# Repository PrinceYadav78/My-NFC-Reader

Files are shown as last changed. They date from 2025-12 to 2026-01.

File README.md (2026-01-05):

# ESP32 NFC Reader

This is my very own prototype of an NFC Reader, built using the ESP32 microcontroller! It’s a compact, wireless module designed to read and interact with NFC tags and cards.

# How to Use
Plug in a USB cable into the receptacle. Install the ESP32IDE for configuration of the firmware.

# Images

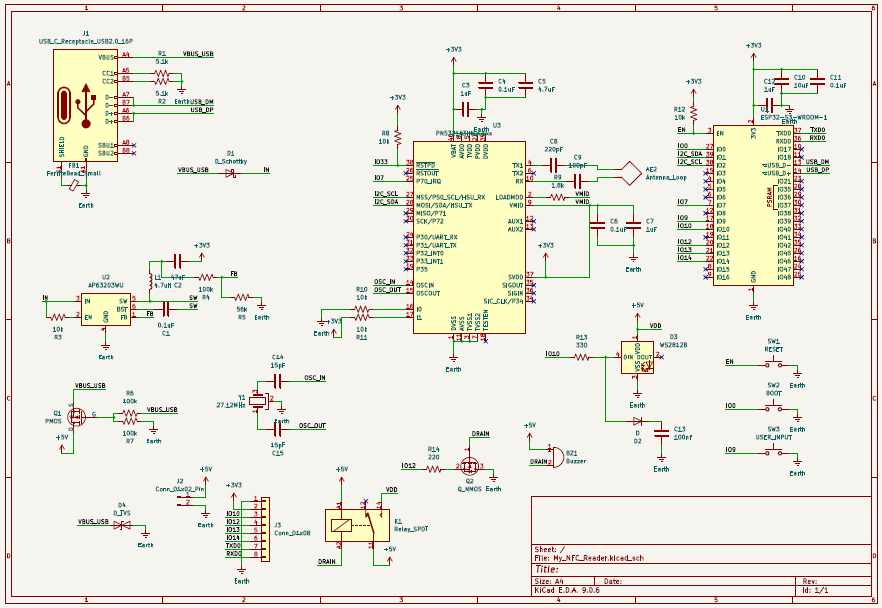
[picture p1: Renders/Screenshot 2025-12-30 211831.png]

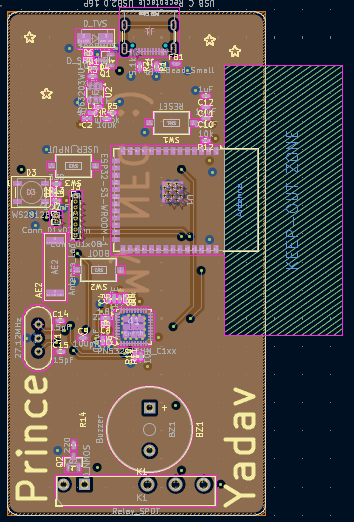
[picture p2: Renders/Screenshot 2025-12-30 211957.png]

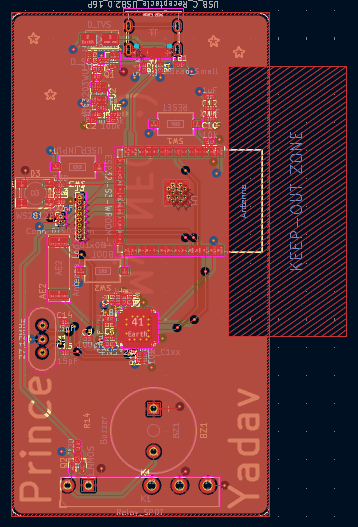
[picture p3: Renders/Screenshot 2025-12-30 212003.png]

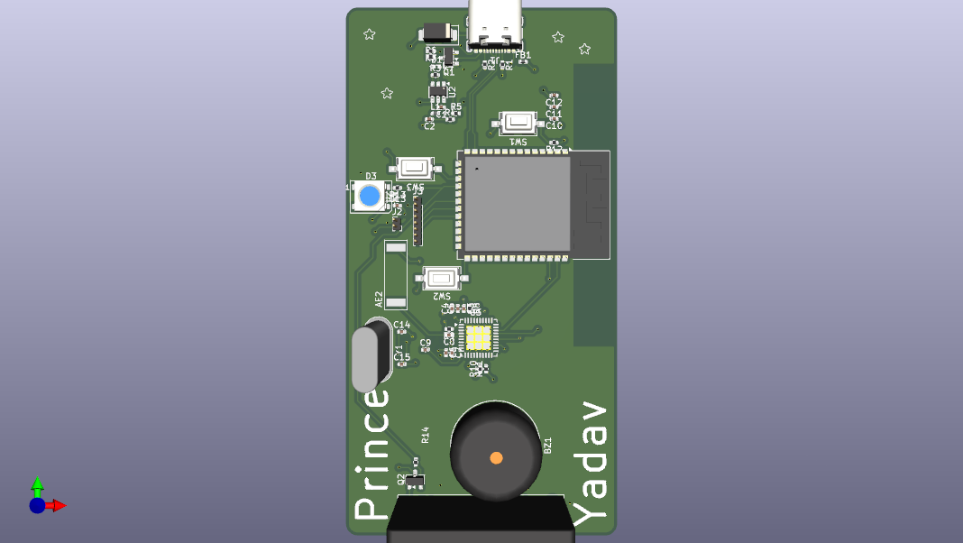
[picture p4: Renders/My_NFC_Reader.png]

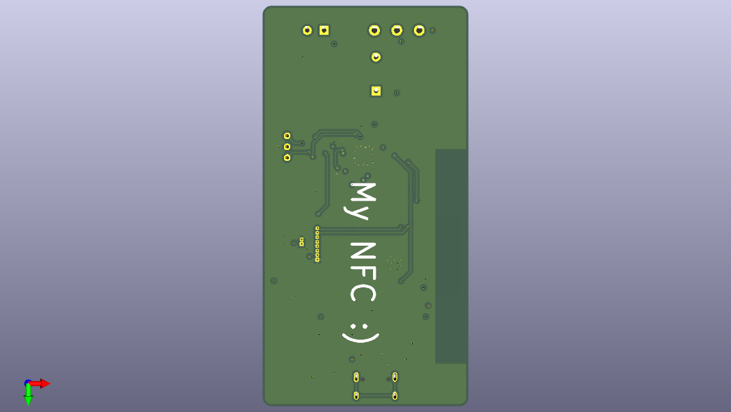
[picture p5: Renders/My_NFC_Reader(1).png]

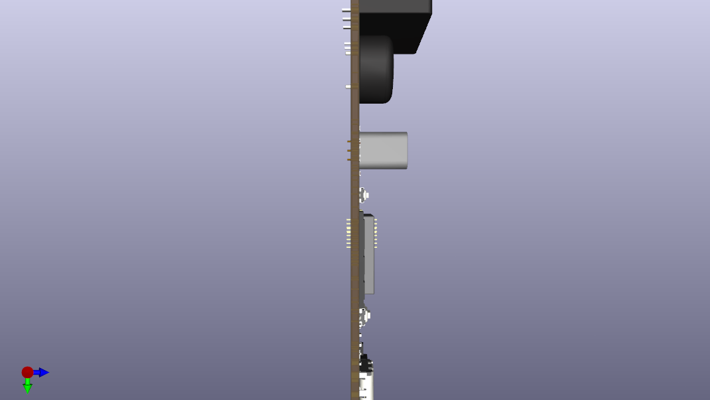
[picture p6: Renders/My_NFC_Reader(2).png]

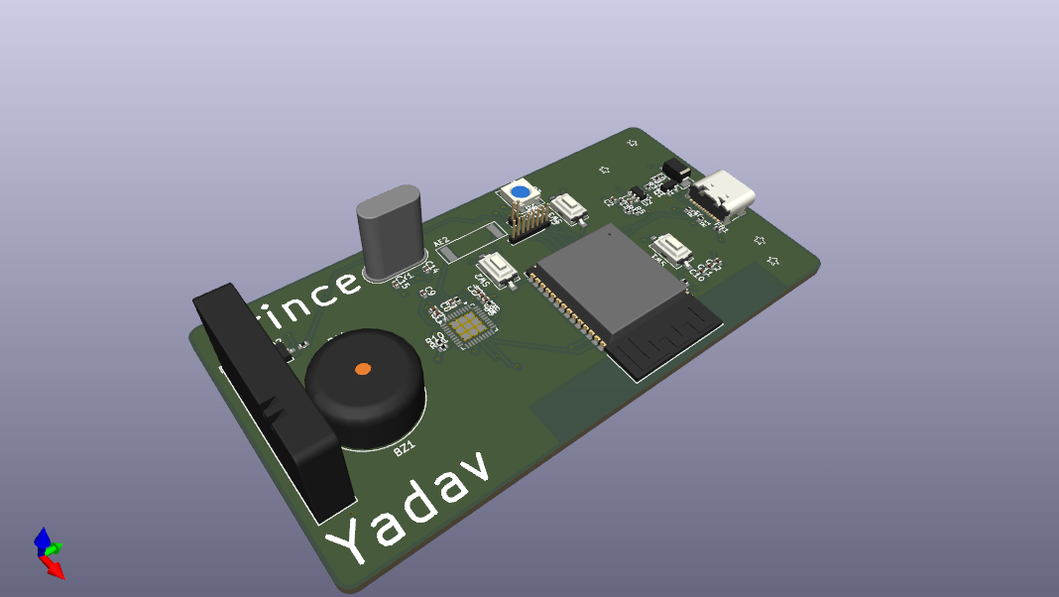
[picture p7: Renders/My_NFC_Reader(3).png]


# BOM
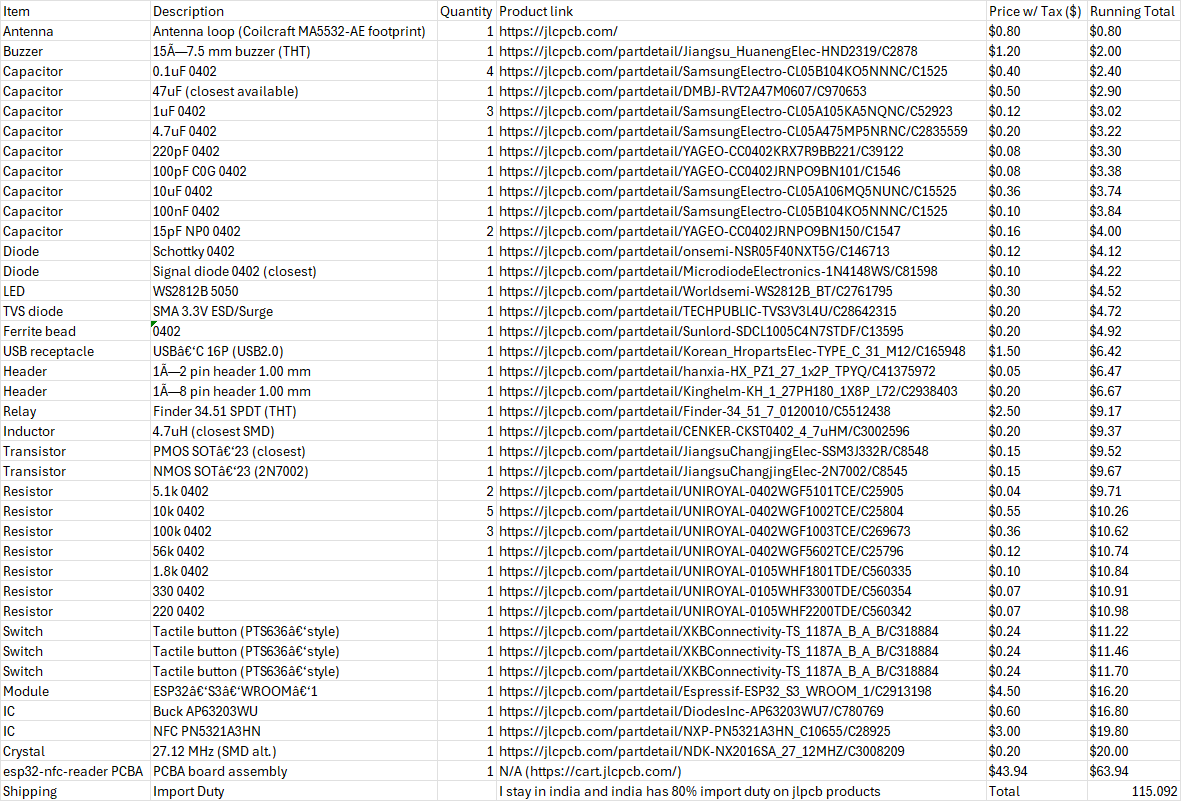
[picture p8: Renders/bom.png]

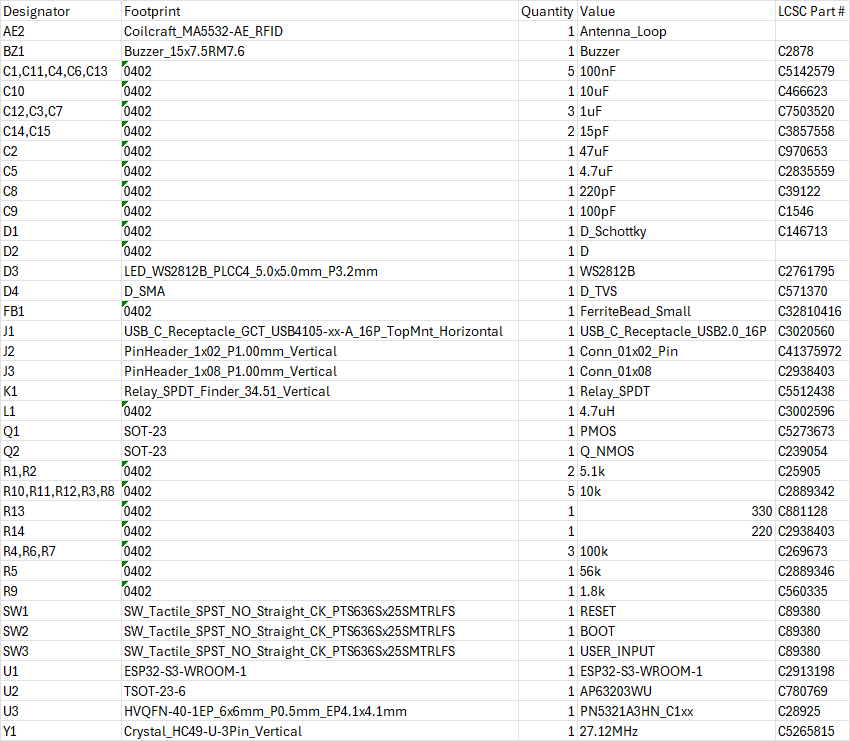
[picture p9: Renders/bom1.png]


## Cart



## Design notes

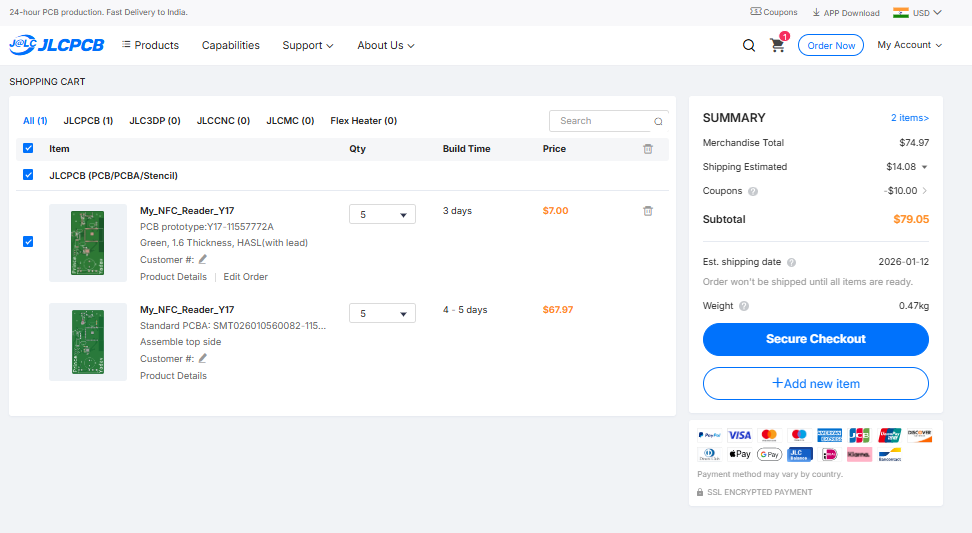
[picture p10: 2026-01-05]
Renders/Screenshot 2026-01-05 065034.png

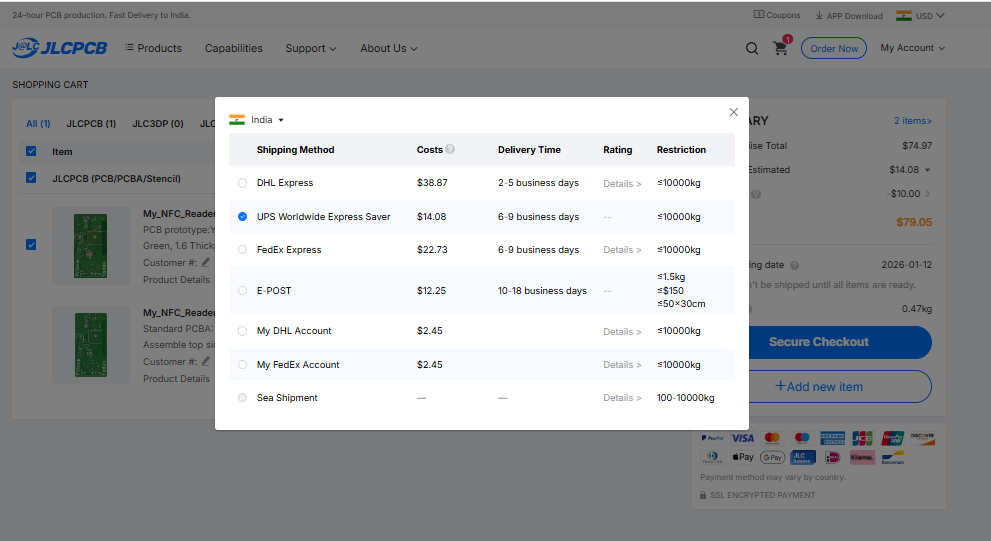
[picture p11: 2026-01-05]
Renders/Screenshot 2026-01-05 065027.png

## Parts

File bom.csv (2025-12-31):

Item | Description | Quantity | Product link | Price w/ Tax ($) | Running Total
Antenna | Antenna loop (Coilcraft MA5532-AE footprint) | 1 | https://jlcpcb.com/ | $0.80 | $0.80
Buzzer | 15×7.5 mm buzzer (THT) | 1 | https://jlcpcb.com/partdetail/Jiangsu_HuanengElec-HND2319/C2878 | $1.20 | $2.00
Capacitor | 0.1uF 0402 | 4 | https://jlcpcb.com/partdetail/SamsungElectro-CL05B104KO5NNNC/C1525 | $0.40 | $2.40
Capacitor | 47uF (closest available) | 1 | https://jlcpcb.com/partdetail/DMBJ-RVT2A47M0607/C970653 | $0.50 | $2.90
Capacitor | 1uF 0402 | 3 | https://jlcpcb.com/partdetail/SamsungElectro-CL05A105KA5NQNC/C52923 | $0.12 | $3.02
Capacitor | 4.7uF 0402 | 1 | https://jlcpcb.com/partdetail/SamsungElectro-CL05A475MP5NRNC/C2835559 | $0.20 | $3.22
Capacitor | 220pF 0402 | 1 | https://jlcpcb.com/partdetail/YAGEO-CC0402KRX7R9BB221/C39122 | $0.08 | $3.30
Capacitor | 100pF C0G 0402 | 1 | https://jlcpcb.com/partdetail/YAGEO-CC0402JRNPO9BN101/C1546 | $0.08 | $3.38
Capacitor | 10uF 0402 | 1 | https://jlcpcb.com/partdetail/SamsungElectro-CL05A106MQ5NUNC/C15525 | $0.36 | $3.74
Capacitor | 100nF 0402 | 1 | https://jlcpcb.com/partdetail/SamsungElectro-CL05B104KO5NNNC/C1525 | $0.10 | $3.84
Capacitor | 15pF NP0 0402 | 2 | https://jlcpcb.com/partdetail/YAGEO-CC0402JRNPO9BN150/C1547 | $0.16 | $4.00
Diode | Schottky 0402 | 1 | https://jlcpcb.com/partdetail/onsemi-NSR05F40NXT5G/C146713 | $0.12 | $4.12
Diode | Signal diode 0402 (closest) | 1 | https://jlcpcb.com/partdetail/MicrodiodeElectronics-1N4148WS/C81598 | $0.10 | $4.22
LED | WS2812B 5050 | 1 | https://jlcpcb.com/partdetail/Worldsemi-WS2812B_BT/C2761795 | $0.30 | $4.52
TVS diode | SMA 3.3V ESD/Surge | 1 | https://jlcpcb.com/partdetail/TECHPUBLIC-TVS3V3L4U/C28642315 | $0.20 | $4.72
Ferrite bead | 0402 | 1 | https://jlcpcb.com/partdetail/Sunlord-SDCL1005C4N7STDF/C13595 | $0.20 | $4.92
USB receptacle | USB‑C 16P (USB2.0) | 1 | https://jlcpcb.com/partdetail/Korean_HropartsElec-TYPE_C_31_M12/C165948 | $1.50 | $6.42
Header | 1×2 pin header 1.00 mm | 1 | https://jlcpcb.com/partdetail/hanxia-HX_PZ1_27_1x2P_TPYQ/C41375972 | $0.05 | $6.47
Header | 1×8 pin header 1.00 mm | 1 | https://jlcpcb.com/partdetail/Kinghelm-KH_1_27PH180_1X8P_L72/C2938403 | $0.20 | $6.67
Relay | Finder 34.51 SPDT (THT) | 1 | https://jlcpcb.com/partdetail/Finder-34_51_7_0120010/C5512438 | $2.50 | $9.17
Inductor | 4.7uH (closest SMD) | 1 | https://jlcpcb.com/partdetail/CENKER-CKST0402_4_7uHM/C3002596 | $0.20 | $9.37
Transistor | PMOS SOT‑23 (closest) | 1 | https://jlcpcb.com/partdetail/JiangsuChangjingElec-SSM3J332R/C8548 | $0.15 | $9.52
Transistor | NMOS SOT‑23 (2N7002) | 1 | https://jlcpcb.com/partdetail/JiangsuChangjingElec-2N7002/C8545 | $0.15 | $9.67
Resistor | 5.1k 0402 | 2 | https://jlcpcb.com/partdetail/UNIROYAL-0402WGF5101TCE/C25905 | $0.04 | $9.71
Resistor | 10k 0402 | 5 | https://jlcpcb.com/partdetail/UNIROYAL-0402WGF1002TCE/C25804 | $0.55 | $10.26
Resistor | 100k 0402 | 3 | https://jlcpcb.com/partdetail/UNIROYAL-0402WGF1003TCE/C269673 | $0.36 | $10.62
Resistor | 56k 0402 | 1 | https://jlcpcb.com/partdetail/UNIROYAL-0402WGF5602TCE/C25796 | $0.12 | $10.74
Resistor | 1.8k 0402 | 1 | https://jlcpcb.com/partdetail/UNIROYAL-0105WHF1801TDE/C560335 | $0.10 | $10.84
Resistor | 330 0402 | 1 | https://jlcpcb.com/partdetail/UNIROYAL-0105WHF3300TDE/C560354 | $0.07 | $10.91
Resistor | 220 0402 | 1 | https://jlcpcb.com/partdetail/UNIROYAL-0105WHF2200TDE/C560342 | $0.07 | $10.98
Switch | Tactile button (PTS636‑style) | 1 | https://jlcpcb.com/partdetail/XKBConnectivity-TS_1187A_B_A_B/C318884 | $0.24 | $11.22
Switch | Tactile button (PTS636‑style) | 1 | https://jlcpcb.com/partdetail/XKBConnectivity-TS_1187A_B_A_B/C318884 | $0.24 | $11.46
Switch | Tactile button (PTS636‑style) | 1 | https://jlcpcb.com/partdetail/XKBConnectivity-TS_1187A_B_A_B/C318884 | $0.24 | $11.70
Module | ESP32‑S3‑WROOM‑1 | 1 | https://jlcpcb.com/partdetail/Espressif-ESP32_S3_WROOM_1/C2913198 | $4.50 | $16.20
IC | Buck AP63203WU | 1 | https://jlcpcb.com/partdetail/DiodesInc-AP63203WU7/C780769 | $0.60 | $16.80
IC | NFC PN5321A3HN | 1 | https://jlcpcb.com/partdetail/NXP-PN5321A3HN_C10655/C28925 | $3.00 | $19.80
Crystal | 27.12 MHz (SMD alt.) | 1 | https://jlcpcb.com/partdetail/NDK-NX2016SA_27_12MHZ/C3008209 | $0.20 | $20.00
esp32-nfc-reader PCBA | PCBA board assembly | 1 | N/A (https://cart.jlcpcb.com/) | $43.94 | $63.94
Shipping | Import Duty |  | I stay in india and india has 80% import duty on jlpcb products | Total | 115.092

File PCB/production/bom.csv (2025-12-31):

Designator | Footprint | Quantity | Value | LCSC Part #
AE2 | Coilcraft_MA5532-AE_RFID | 1 | Antenna_Loop
BZ1 | Buzzer_15x7.5RM7.6 | 1 | Buzzer
C1, C11, C4, C6 | 0402 | 4 | 0.1uF
C10 | 0402 | 1 | 10uF
C12, C3, C7 | 0402 | 3 | 1uF
C13 | 0402 | 1 | 100nF
C14, C15 | 0402 | 2 | 15pF
C2 | 0402 | 1 | 47uF
C5 | 0402 | 1 | 4.7uF
C8 | 0402 | 1 | 220pF
C9 | 0402 | 1 | 100pF
D1 | 0402 | 1 | D_Schottky
D2 | 0402 | 1 | D
D3 | LED_WS2812B_PLCC4_5.0x5.0mm_P3.2mm | 1 | WS2812B
D4 | D_SMA | 1 | D_TVS
FB1 | 0402 | 1 | FerriteBead_Small
J1 | USB_C_Receptacle_GCT_USB4105-xx-A_16P_TopMnt_Horizontal | 1 | USB_C_Receptacle_USB2.0_16P
J2 | PinHeader_1x02_P1.00mm_Vertical | 1 | Conn_01x02_Pin
J3 | PinHeader_1x08_P1.00mm_Vertical | 1 | Conn_01x08
K1 | Relay_SPDT_Finder_34.51_Vertical | 1 | Relay_SPDT
L1 | 0402 | 1 | 4.7uH
Q1 | SOT-23 | 1 | PMOS
Q2 | SOT-23 | 1 | Q_NMOS
R1, R2 | 0402 | 2 | 5.1k
R10, R11, R12, R3, R8 | 0402 | 5 | 10k
R13 | 0402 | 1 | 330
R14 | 0402 | 1 | 220
R4, R6, R7 | 0402 | 3 | 100k
R5 | 0402 | 1 | 56k
R9 | 0402 | 1 | 1.8k
SW1 | SW_Tactile_SPST_NO_Straight_CK_PTS636Sx25SMTRLFS | 1 | RESET
SW2 | SW_Tactile_SPST_NO_Straight_CK_PTS636Sx25SMTRLFS | 1 | BOOT
SW3 | SW_Tactile_SPST_NO_Straight_CK_PTS636Sx25SMTRLFS | 1 | USER_INPUT
U1 | ESP32-S3-WROOM-1 | 1 | ESP32-S3-WROOM-1
U2 | TSOT-23-6 | 1 | AP63203WU
U3 | HVQFN-40-1EP_6x6mm_P0.5mm_EP4.1x4.1mm | 1 | PN5321A3HN_C1xx
Y1 | Crystal_HC49-U-3Pin_Vertical | 1 | 27.12MHz

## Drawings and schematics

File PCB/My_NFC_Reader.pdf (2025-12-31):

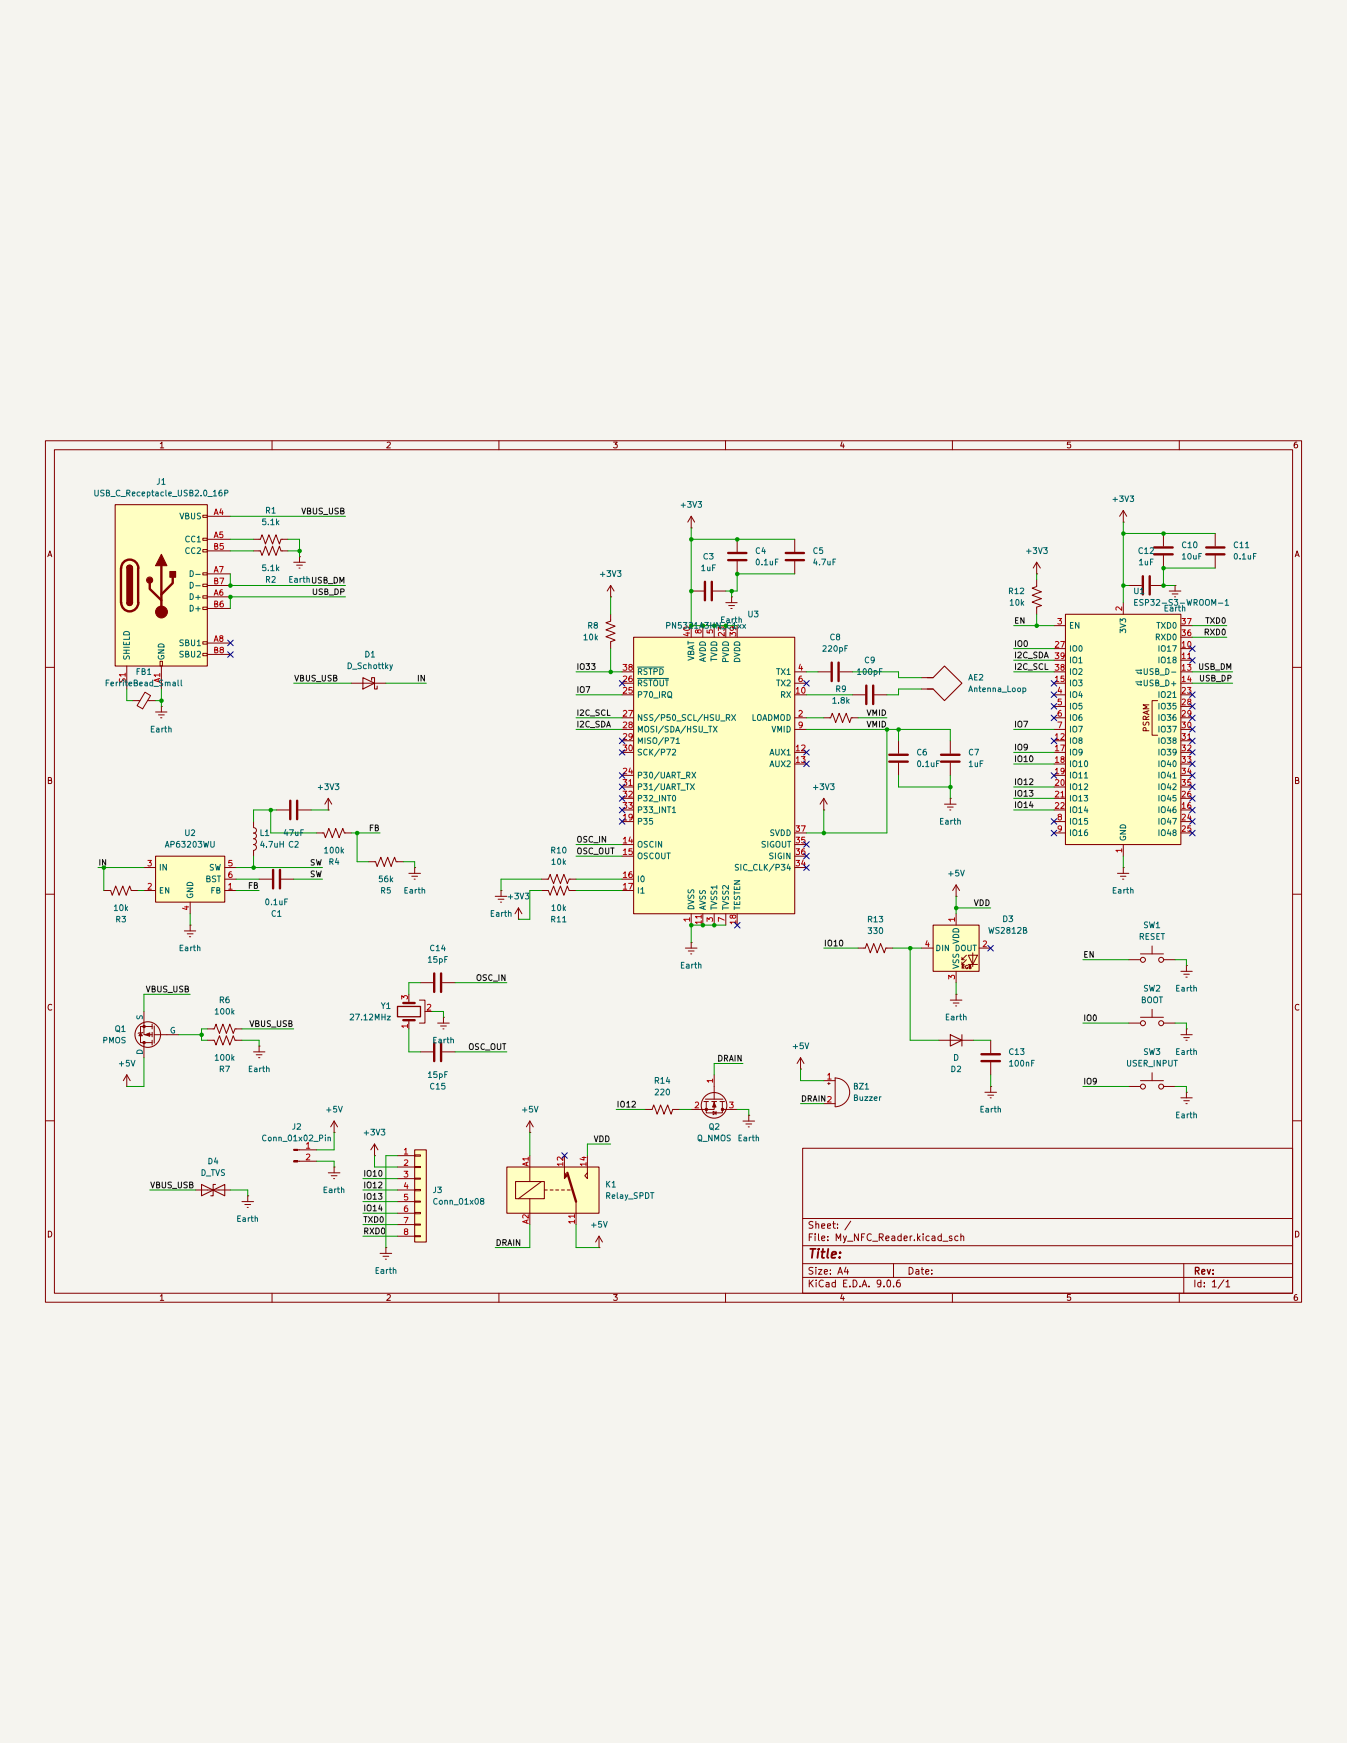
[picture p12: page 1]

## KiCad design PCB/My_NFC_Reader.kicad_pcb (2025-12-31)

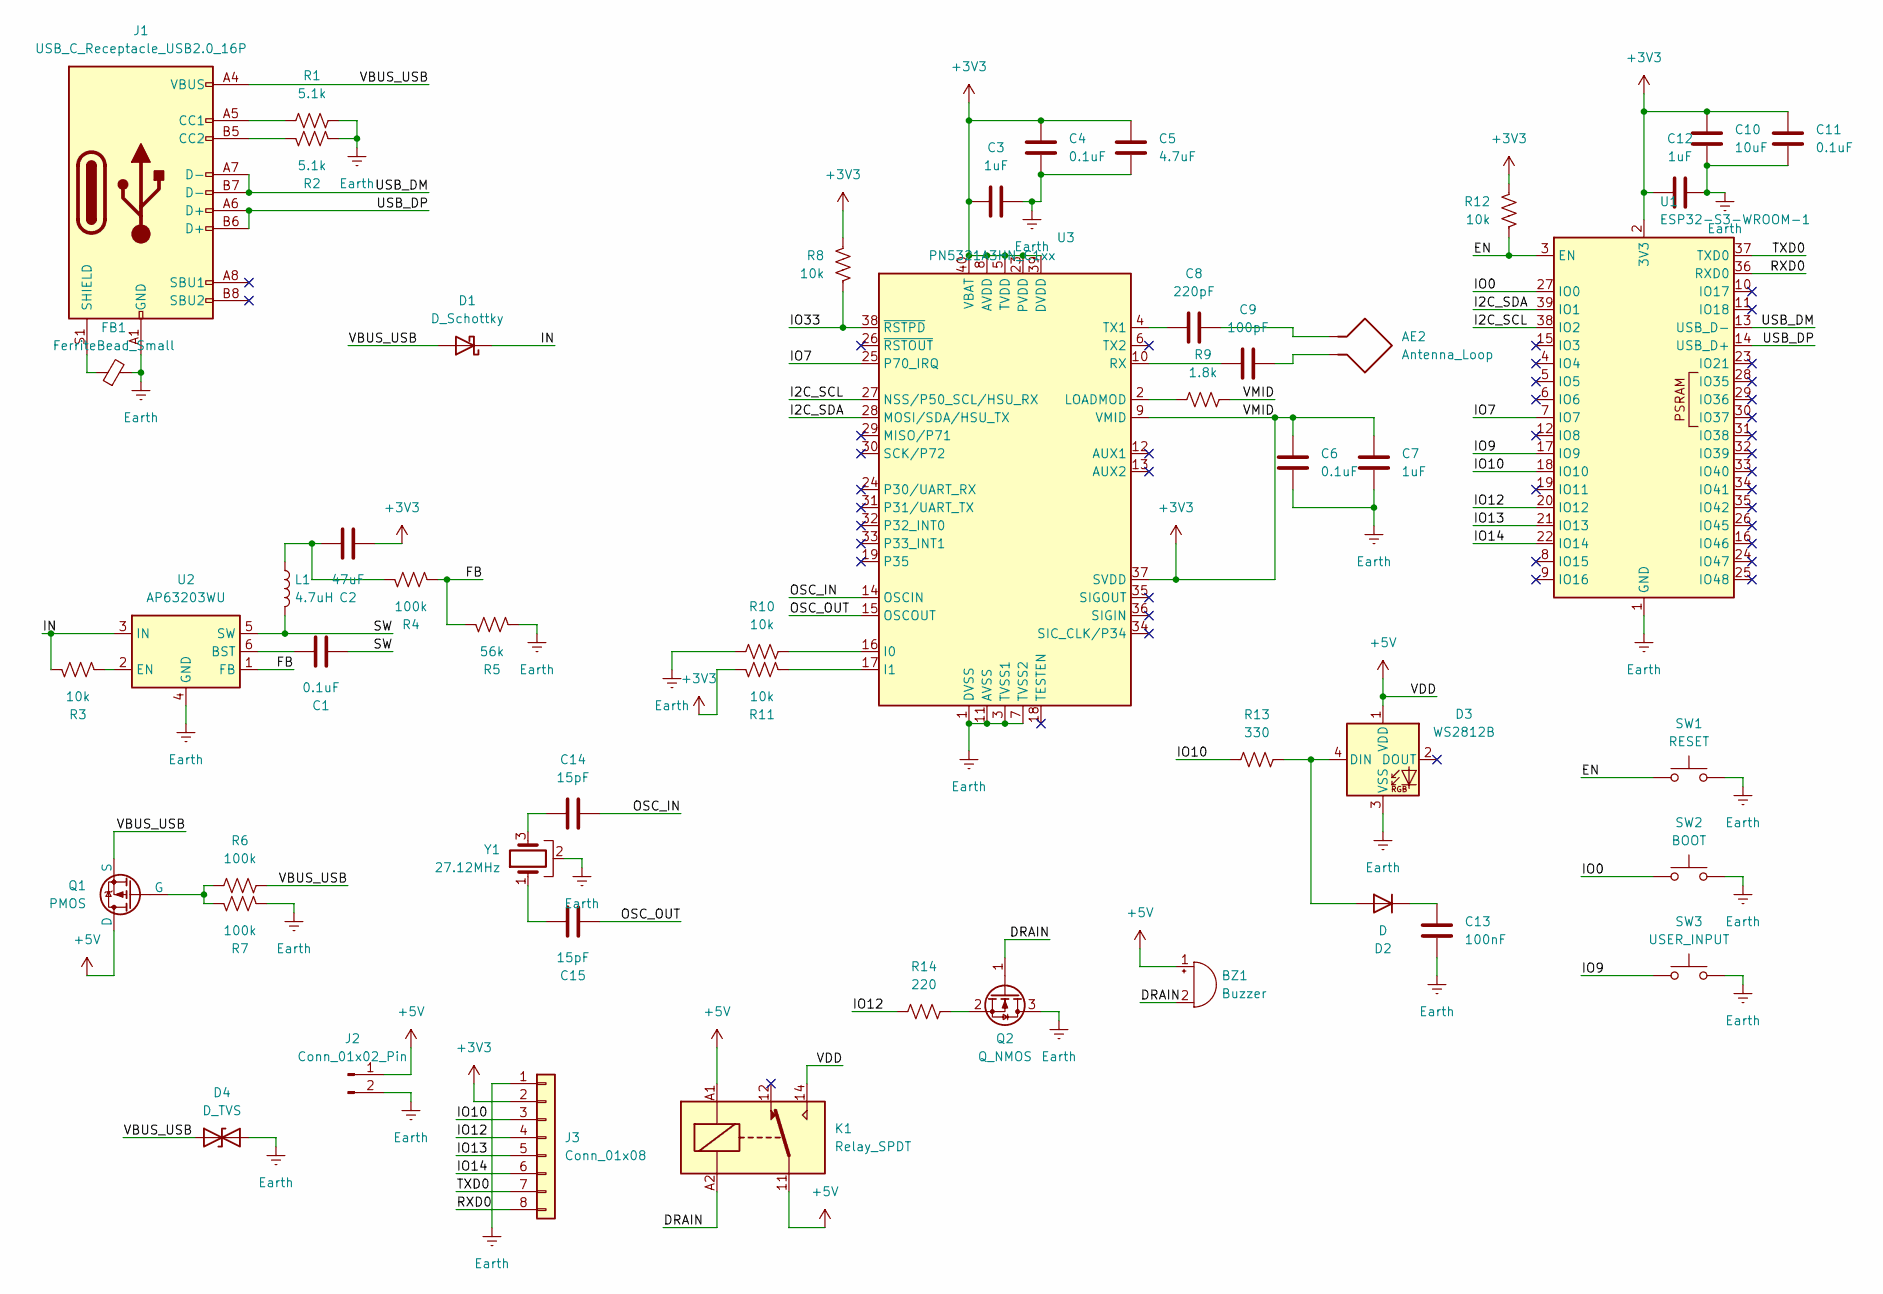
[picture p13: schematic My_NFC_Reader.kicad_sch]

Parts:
AE2: Antenna_Loop; Coilcraft_MA5532-AE_RFID
BZ1: Buzzer; Buzzer_15x7.5RM7.6
C1, C4, C6, C11: 0.1uF; C_0402_1005Metric
C2: 47uF; C_0402_1005Metric
C3, C7, C12: 1uF; C_0402_1005Metric
C5: 4.7uF; C_0402_1005Metric
C8: 220pF; C_0402_1005Metric
C9: 100pF; C_0402_1005Metric
C10: 10uF; C_0402_1005Metric
C13: 100nF; C_0402_1005Metric
C14, C15: 15pF; C_0402_1005Metric
D1: D_Schottky; D_0402_1005Metric
D2: D; D_0402_1005Metric
D3: WS2812B; LED_WS2812B_PLCC4_5.0x5.0mm_P3.2mm
D4: D_TVS; D_SMA
FB1: FerriteBead_Small; L_0402_1005Metric
J1: USB_C_Receptacle_USB2.0_16P; USB_C_Receptacle_GCT_USB4105-xx-A_16P_TopMnt_Horizontal
J2: Conn_01x02_Pin; PinHeader_1x02_P1.00mm_Vertical
J3: Conn_01x08; PinHeader_1x08_P1.00mm_Vertical
K1: Relay_SPDT; Relay_SPDT_Finder_34.51_Vertical
L1: 4.7uH; L_0402_1005Metric
Q1: PMOS; SOT-23
Q2: Q_NMOS; SOT-23
R1, R2: 5.1k; R_0402_1005Metric
R3, R8, R10, R11, R12: 10k; R_0402_1005Metric
R4, R6, R7: 100k; R_0402_1005Metric
R5: 56k; R_0402_1005Metric
R9: 1.8k; R_0402_1005Metric
R13: 330; R_0402_1005Metric
R14: 220; R_0402_1005Metric
SW1: RESET; SW_Tactile_SPST_NO_Straight_CK_PTS636Sx25SMTRLFS
SW2: BOOT; SW_Tactile_SPST_NO_Straight_CK_PTS636Sx25SMTRLFS
SW3: USER_INPUT; SW_Tactile_SPST_NO_Straight_CK_PTS636Sx25SMTRLFS
U1: ESP32-S3-WROOM-1
U2: AP63203WU; TSOT-23-6
U3: PN5321A3HN_C1xx; HVQFN-40-1EP_6x6mm_P0.5mm_EP4.1x4.1mm
Y1: 27.12MHz; Crystal_HC49-U-3Pin_Vertical

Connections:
+3V3: C2.2, C3.1, C4.2, C5.2, C6.1, C7.1, C10.1, C11.1, C12.1, J3.2, R8.1, R9.2, R11.1, R12.1, U1.2 (3V3), U3.5 (TVDD), U3.8 (AVDD), U3.9 (VMID), U3.23 (PVDD), U3.37 (SVDD), U3.39 (DVDD), U3.40 (VBAT)
+5V: BZ1.1 (+), D3.1 (VDD), J2.1, K1.11, K1.14, K1.A1, Q1.1 (D)
/DRAIN: BZ1.2 (-), K1.A2, Q2.1 (G)
/EN: R12.2, SW1.1, U1.3 (EN)
/FB: R4.2, R5.1, U2.1 (FB)
/I2C_SCL: U1.38 (IO2), U3.27 (NSS/P50_SCL/HSU_RX)
/I2C_SDA: U1.39 (IO1), U3.28 (MOSI/SDA/HSU_TX)
/IN: D1.1 (K), R3.1, U2.3 (IN)
/IO0: SW2.1, U1.27 (IO0)
/IO7: U1.7 (IO7), U3.25 (P70_IRQ)
/IO9: SW3.1, U1.17 (IO9)
/IO10: J3.3, R13.1, U1.18 (IO10)
/IO12: J3.4, R14.1, U1.20 (IO12)
/IO13: J3.5, U1.21 (IO13)
/IO14: J3.6, U1.22 (IO14)
/IO33: R8.2, U3.38 (~RSTPD)
/OSC_IN: C14.2, U3.14 (OSCIN)
/OSC_OUT: C15.2, U3.15 (OSCOUT)
/RXD0: J3.8, U1.36 (RXD0)
/SW: C1.2, L1.2, U2.5 (SW)
/TXD0: J3.7, U1.37 (TXD0)
/USB_DM: J1.A7 (D-), J1.B7 (D-), U1.13 (USB_D-)
/USB_DP: J1.A6 (D+), J1.B6 (D+), U1.14 (USB_D+)
/VBUS_USB: D1.2 (A), D4.1 (A1), J1.A4 (VBUS), J1.A9 (VBUS), J1.B4 (VBUS), J1.B9 (VBUS), Q1.3 (S), R6.2
Earth: C3.2, C4.1, C5.1, C6.2, C7.2, C10.2, C11.2, C12.2, C13.2, D3.3 (VSS), D4.2 (A2), FB1.2, J1.A1 (GND), J1.A12 (GND), J1.B1 (GND), J1.B12 (GND), J2.2, J3.1, Q2.3 (D), R1.2, R2.2, R5.2, R7.1, R10.1, SW1.2, SW2.2, SW3.2, U1.1 (GND), U1.40 (GND), U1.41 (GND), U2.4 (GND), U3.1 (DVSS), U3.3 (TVSS1), U3.7 (TVSS2), U3.11 (AVSS), U3.41 (AVSS), Y1.2
unnamed: AE2.1, C8.2
unnamed: AE2.2, C9.1
unnamed: C2.1, L1.1, R4.1
unnamed: C14.1, Y1.3
unnamed: C15.1, Y1.1
unnamed: D2.2 (A), D3.4 (DIN), R13.2
unnamed: C13.1, D2.1 (K)
unnamed: J1.A5 (CC1), R1.1
unnamed: J1.B5 (CC2), R2.1
unnamed: FB1.1, J1.S1 (SHIELD)
unnamed: Q1.2 (G), R6.1, R7.2
unnamed: Q2.2 (S), R14.2
unnamed: C1.1, U2.6 (BST)
unnamed: R3.2, U2.2 (EN)
unnamed: R10.2, U3.16 (I0)
unnamed: R11.2, U3.17 (I1)
unnamed: R9.1, U3.2 (LOADMOD)
unnamed: C9.2, U3.10 (RX)
unnamed: C8.1, U3.4 (TX1)

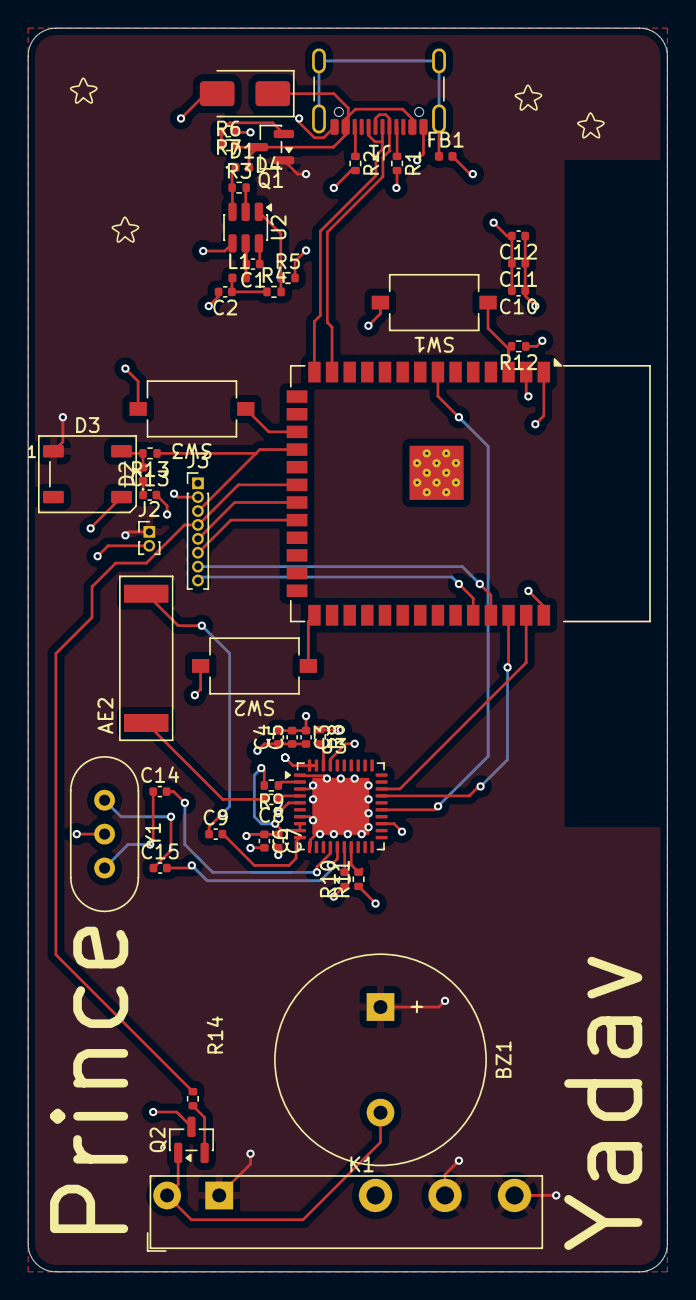
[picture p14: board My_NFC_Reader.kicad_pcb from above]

Board: 4 copper layers, 46.0 x 89.5 mm, 50 parts (0 on the bottom side), 44 nets.

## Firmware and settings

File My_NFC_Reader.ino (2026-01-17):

#include <Wire.h>
#include <PN532_I2C.h>
#include <PN532.h>

#define SDA_PIN 8
#define SCL_PIN 9
#define PN532_RST 10
#define PN532_IRQ 7

#define BUZZER_PIN 12
#define RELAY_PIN 11

PN532_I2C pn532_i2c(Wire);
PN532 nfc(pn532_i2c);

void setup() {
  Serial.begin(115200);
  delay(1000);

  pinMode(BUZZER_PIN, OUTPUT);
  pinMode(RELAY_PIN, OUTPUT);

  digitalWrite(BUZZER_PIN, LOW);
  digitalWrite(RELAY_PIN, LOW);

  Wire.begin(SDA_PIN, SCL_PIN);

  Serial.println("Starting NFC Reader...");

  nfc.begin();

  uint32_t version = nfc.getFirmwareVersion();
  if (!version) {
    Serial.println("PN532 NOT FOUND");
    while (1);
  }

  Serial.print("PN532 Firmware: ");
  Serial.println((version >> 16) & 0xFF, HEX);

  nfc.SAMConfig();
  Serial.println("Waiting for NFC card...");
}

void loop() {
  uint8_t uid[7];
  uint8_t uidLength;

  bool success = nfc.readPassiveTargetID(
    PN532_MIFARE_ISO14443A,
    uid,
    &uidLength
  );

  if (success) {
    Serial.print("Card UID: ");
    for (uint8_t i = 0; i < uidLength; i++) {
      Serial.print(uid[i], HEX);
      Serial.print(" ");
    }
    Serial.println();

    // Beep
    digitalWrite(BUZZER_PIN, HIGH);
    delay(100);
    digitalWrite(BUZZER_PIN, LOW);

    // Relay ON
    digitalWrite(RELAY_PIN, HIGH);
    delay(1000);
    digitalWrite(RELAY_PIN, LOW);

    delay(1500);
  }
}
